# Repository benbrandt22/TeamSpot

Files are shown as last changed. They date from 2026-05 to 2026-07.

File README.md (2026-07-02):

# TeamSpot

Hardware Mute Control for Microsoft Teams

(Currently a work in progress)

## Why does this exist?

This project was created because it seemed like a fun idea for a small electronics project to try some new things. In my professional life, I use Microsoft Teams for meetings and calls. During most meetings I try to have good microphone etiquette, muting myself when I'm not speaking to minimize background noise and distractions for others. When I wanted to speak, I didn't like having to grab my mouse and find the un-mute button. Sometimes that meant extra seconds of silence before I could respond. Sometimes I'd forget I'm on mute because I had another appication active. Keyboard shortcuts didn't seem like the right solution either, as sometimes I'm using another application that's active in front of MS Teams. I was in the mood to build some hardware, so a physical button seemed like the right way to handle this.

The other key objective was to get good visual feedback of my microphone's current mute status. I wanted the device to reflect the actual status of the microphone in Teams, so that if I muted myself using the software controls, the device would show that as well.

## Hardware

- [Firmware ReadMe](src/firmware/README.md)
- [Circuit Board ReadMe](src/board/README.md)

# Software

- [Windows Service ReadMe](src/service/README.md)

## Teams Integration

My initial research revealed a local websocket API that published realtime events from Teams, and had the ability to send commands to Teams. This was originally released (I think) around 2023 and was heavily used by the Elgato Stream Deck to allow similar control and status display integration with Teams.

This local Teams API can be seen in MS Teams under Settings > Privacy > Third-Party app API.

Some related links:
- https://techcommunity.microsoft.com/blog/microsoftteamsblog/delivering-new-webinar-experiences-with-microsoft-teams/3725145
- https://github.com/malkstar/ms_teams_websockets
- https://github.com/svrooij/teams-monitor/issues/15
- https://github.com/svrooij/teams-monitor
- https://support.microsoft.com/en-us/office/connect-to-third-party-devices-in-microsoft-teams-aabca9f2-47bb-407f-9f9b-81a104a883d6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
- https://lostdomain.notion.site/Microsoft-Teams-WebSocket-API-5c042838bc3e4731bdfe679e864ab52a

When I discovered this, I also found articles/posts that revealed that Microsoft was planning on deprecating and/or removing this API, announced in late 2025. The Teams instance on my personal computer did not have this API enabled. However, my Teams installation on my work laptop did have it enabled. They were both on the same version, so something about my corporate account had this feature enabled. It could still go away someday, but for now it works and that's good enough for my little project.

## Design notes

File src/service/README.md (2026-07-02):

# TeamSpot Windows Service

This project is a Windows Service application designed to connect to Microsoft Teams as well as the TeamSpot USB device. Based on the currect state of MS Teams, this service will set the LED color on the device. This service also receives button press events from the device and reacts accordingly by sending messages to Teams to Mute or Unmute.

This service supports two types of button presses on the device:

- Short button press (1 second or less): This will toggle the mute state in Microsoft Teams. Useful for quickly muting or unmuting during a call.
- Long button press (over 1 second): This will temporarily toggle the mute state only while the button is held down. Useful when you want to temporarily mute yourself to cough, or briefly unmute for a short comment.

## How to Build/Compile

This project is set up to publish to a single executable file which can then be used as a Windows Service. To produce this executable, do one of the following:

- Using Visual Studio, right click on the `TeamSpot.Service` project and select "Publish". The Folder publish profile will be selected by default. Click the "Publish" button to create the output.
- Form a command line, navigate to the `TeamSpot.Service` project folder and run the following command:
  ```
  dotnet publish -p:PublishProfile=FolderProfile
  ```

The executable and accompanying files will be placed in the `TeamSpot.Service\bin\Release\net10.0-windows\win-x64\publish\win-x64` folder of the project. You can then use this output to install the service on your Windows machine.

## How to Install

I haven't created a proper installer for this service. Since this is currently just for me it's simple enough to manually install the executable as a Windows Service. I've simplified the process by including a script. Simply run the `install-service.bat` script included in the build output folder. You may need Administrator privileges to run this script. Within Windows, right-click on the script and select "*Run as Administrator*". This script will install the service and start it automatically. If you wish to uninstall, run the `uninstall-service.bat` script in the same manner.

## LED Color Adjustment

If you wish to change to default LED colors shown on the button for each possible state, edit the color values in the `appsettings.json` file. Colors are represented in RGB values (0-255 for each channel) as well as a brightness value of 0 to 100. The application is set up to auto-update settings if they are changed, so you can edit the file while the service is running and it will pick up the changes automatically and update the LED within a few seconds.

## Development Notes

The windows service itself is composed of a series of C# BackgroundService implementations. The main jobs of the service (listening to a Websocket API, and listening for USB device messages) are asynchronous operations that block until a message comes in. This is a challenge for communicating back and forth between the various internal services. The communication challenge is handled using ChannelReader and ChannelWriter objects to allow these async services to communicate across threads. Admittedly this is a fairly new pattern to me, so I had some help from AI to get it scaffolded out, but after working with it and refactoring it, it's been working well for this project.

Windows service project fundamentals:
- https://learn.microsoft.com/en-us/dotnet/core/extensions/windows-service

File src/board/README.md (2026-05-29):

# Circuit Board

The circuit board was designed with [KiCad](https://www.kicad.org/). I've designed boards in the past with other tools, and this was my first project in KiCad. With a little help from YouTube tutorials, I was able to get up to speed quickly.

The board contains a mix of surface mount and through-hole components. The RGB LEDs, capacitors, and resistor are all surface mount, while the microcontroller and keyboard switch are through-hole.

The schematic was inspired by the [Adafruit Neopixel Jewel](https://www.adafruit.com/product/2226), which uses a similar circuit to control RGB LEDs. The board arranges 6 WS2812B LEDs in a circular pattern, with a single data line running through each LED. The keyboard switch is soldered to the front of the board in the middle of the LEDs.

The microcontroller is mounted on the back of the board, offset from the board using pin headers/sockets. The five pins opposite of the USB plug are not included in the board design. They are not used in the circuit, and removing them leaves space to mount the keyboard switch.

Two 3mm mounitng holes are included to allow two M3 bolts to hold the board in place.

For my personal build, I ordered boards from [PCBWay](https://www.pcbway.com/) mainly for their hobbyist-friendly pricing. They also provide a KiCad plugin that makes it easy to export and upload design files and order the boards online.

## Useful Links:

- [KiCad](https://www.kicad.org/)
- [Adafruit Neopixel Jewel](https://www.adafruit.com/product/2226)
- [Neopixel Schematics and PCBs](https://learn.adafruit.com/adafruit-neopixel-uberguide/downloads)
- [RP2040-Zero Symbol/Footprint Download](https://www.snapeda.com/parts/RP2040-ZERO/Waveshare%20Electronics/view-part/)
- [PCBWay](https://www.pcbway.com/)
- [PCBWay KiCad Plugin Info](https://www.pcbway.com/blog/News/PCBWay_Plug_In_for_KiCad_3ea6219c.html)

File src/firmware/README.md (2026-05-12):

# Hardware

The hardware is based off of a RP2040-Zero microcontroller, running [CircuitPython](https://circuitpython.org/). I chose this device because:

- Supports USB HID, and I wanted to learn USB communications. USB is also simpler setup on the host PC, as I don't need to worry about choosing and configuring COM ports for serial communication
- Small footprint, so I can easily fit this into a small 3D-printable enclosure
- Low-cost. I found a 3-pack on Amazon for around $10
- CircuitPython support, which I have some past experience with. I really like the easy development-loop experience of just updating script files directly on the device.
- Includes a built-in RGB LED, which I can use for visual feedback (unless I find it's not bright enough on its own)

## Reference Images

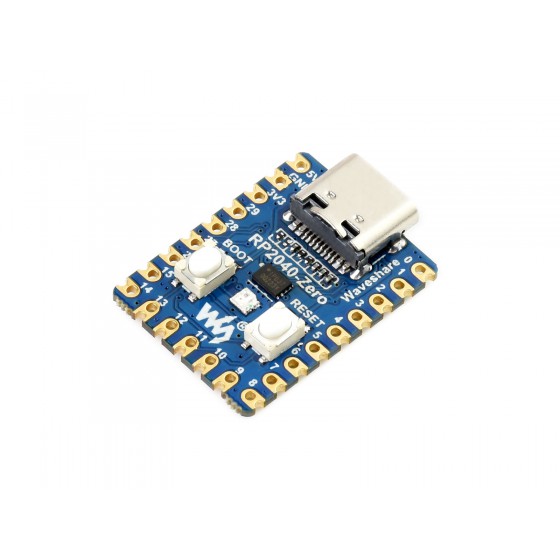
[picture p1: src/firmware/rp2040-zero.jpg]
[](rp2040-zero.jpg)
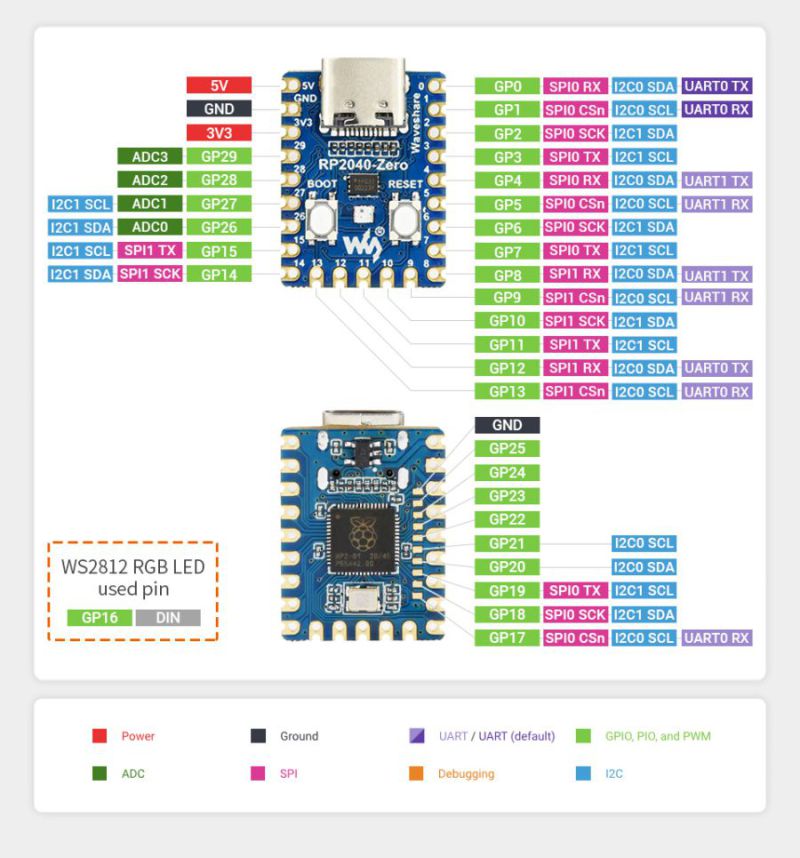
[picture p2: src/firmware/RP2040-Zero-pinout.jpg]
[](RP2040-Zero-pinout.jpg)
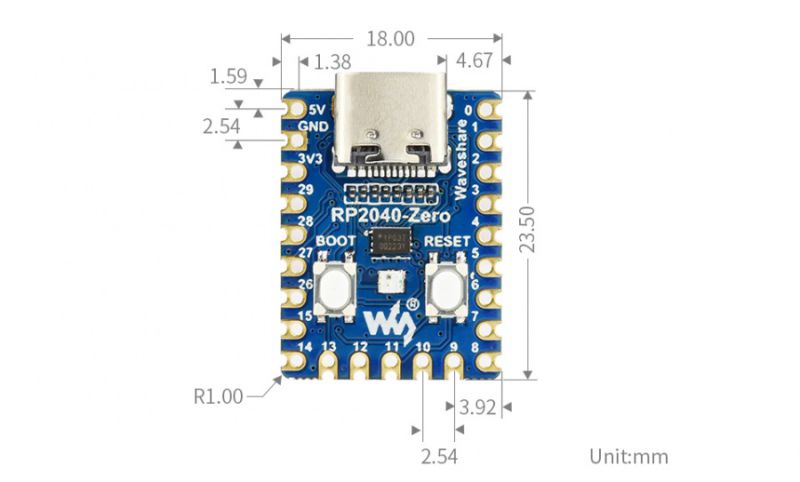
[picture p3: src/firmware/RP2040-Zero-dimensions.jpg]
[](RP2040-Zero-dimensions.jpg)

## Hardware Setup

1. Download the CircuitPython build for the RP2040-Zero: https://circuitpython.org/board/waveshare_rp2040_zero/ (Currently v10.2.0 at the time of this writing)
2. Plug the board into a USB port and copy the downloaded `.uf2` file to the drive of the RP2040-Zero
3. The device will reboot and show up as a new drive called `CIRCUITPY`

## Deploying Code

Source code for the device lives in the `device/src` directory. Make any changes there, and run the `deploy.ps1` powershell script to copy any updated files to the circuitpython drive. The script will find the circuitpython drive and copy files to it.

## USB HID Report Descriptor

USB HID (Human Interface Device) is a standard for devices that interact with humans, such as keyboards, mice, game controllers, etc. The HID report descriptor is a data structure that describes the format of the data that the device will send to the host computer. It defines the types of inputs and outputs the device has, and how they are structured. Generating these descriptors can be complex, and that's where `Waratah` comes in.

Waratah is a tool from Microsoft for generating USB HID descriptors, using a .wara file to define the HID descriptor in a more human-readable way.

Waratah Links & information

- https://github.com/microsoft/hidtools
- https://github.com/microsoft/hidtools/wiki

To install, run the command `winget install Microsoft.HIDTools.Waratah`

In this project, the `hid_descriptor` directory contains a small development environment for building the report descriptor.

- `descriptor.wara` acts as the "source code" for the descriptor
- `generate.ps1` script runs the Waratah tool to build a report descriptor from the .wara file. Waratah by default only generates a C code file, so the powershell script pulls out the raw data and builds a python-compatible byte array that can be copied into the CircuitPython project.

Other relevant USB HID links:

- https://eleccelerator.com/tutorial-about-usb-hid-report-descriptors/
- https://www.usb.org/hid
- https://docs.circuitpython.org/en/latest/shared-bindings/usb_hid/

Web-based HID Explorer tool for testing USB device:

- Github repo: https://github.com/paulirish/webhid-explorer
- Live tool: https://paulirish.github.io/webhid-explorer/

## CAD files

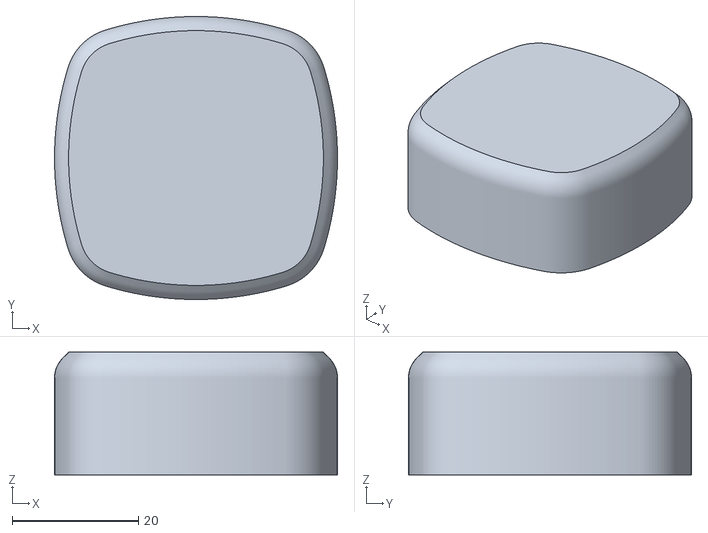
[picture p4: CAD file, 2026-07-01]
src/enclosure/teamspot-button-keycap.stl
44.8 x 44.8 x 19.4

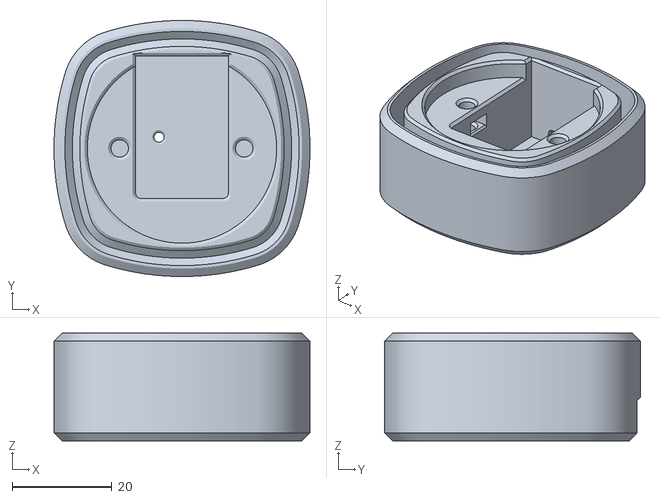
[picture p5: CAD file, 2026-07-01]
src/enclosure/teamspot-base.stl
51.4 x 51.4 x 21.6

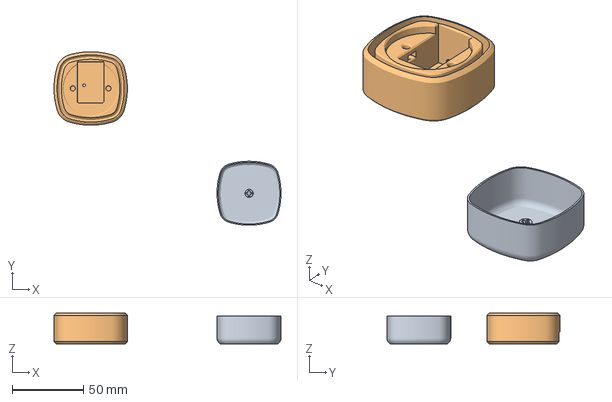
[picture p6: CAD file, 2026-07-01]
src/enclosure/teamspot-enclosure-bambu.3mf
159.0 x 121.4 x 21.6 mm
teamspot-button-keycap.stl
teamspot-base.stl

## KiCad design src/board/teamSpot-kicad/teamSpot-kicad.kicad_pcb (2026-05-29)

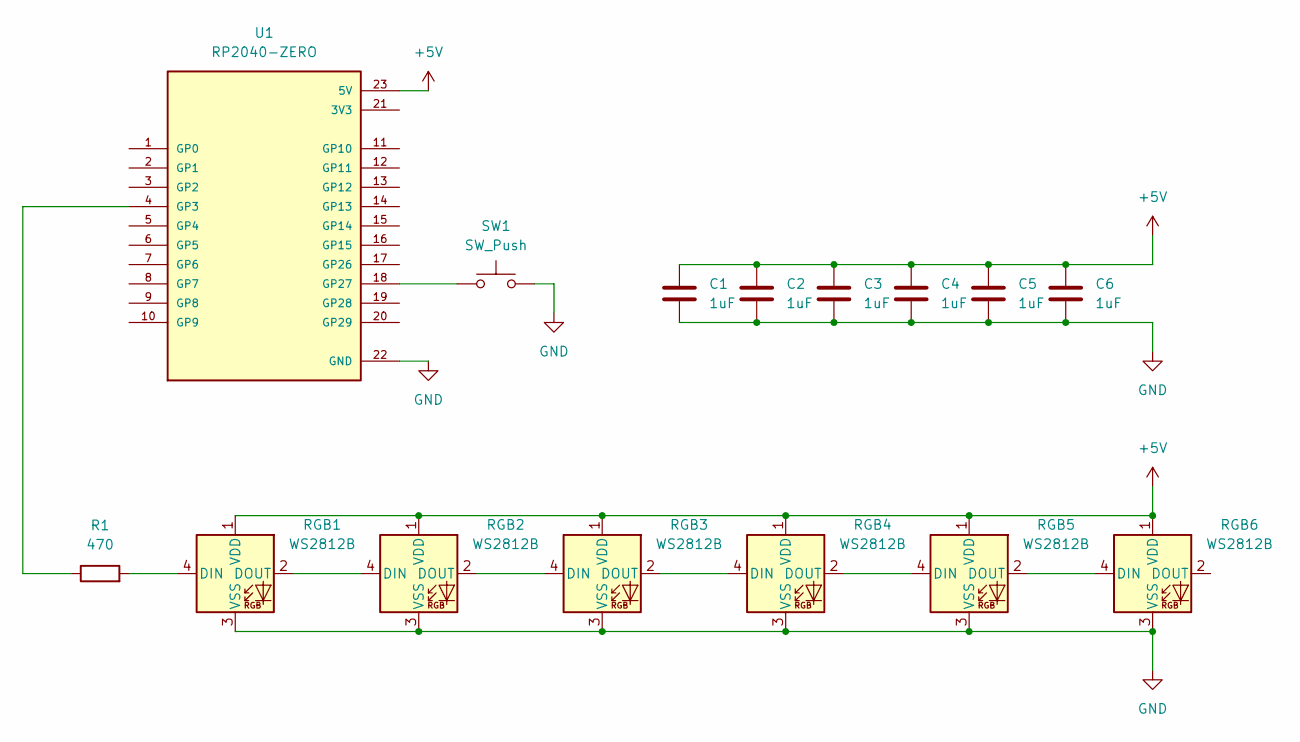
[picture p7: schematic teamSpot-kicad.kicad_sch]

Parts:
C1, C2, C3, C4, C5, C6: 1uF; C_0603_1608Metric
R1: 470; R_0603_1608Metric
RGB1, RGB2, RGB3, RGB4, RGB5, RGB6: WS2812B; LED_WS2812B_PLCC4_5.0x5.0mm_P3.2mm
SW1: SW_Push; SW_Cherry_MX_1.00u_PCB
U1: RP2040-ZERO; MODULE_RP2040-ZERO-SIDES-ONLY; PARTREV NA

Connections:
+5V: C1.1, C2.1, C3.1, C4.1, C5.1, C6.1, RGB1.1 (VDD), RGB2.1 (VDD), RGB3.1 (VDD), RGB4.1 (VDD), RGB5.1 (VDD), RGB6.1 (VDD), U1.23 (5V)
GND: C1.2, C2.2, C3.2, C4.2, C5.2, C6.2, RGB1.3 (VSS), RGB2.3 (VSS), RGB3.3 (VSS), RGB4.3 (VSS), RGB5.3 (VSS), RGB6.3 (VSS), SW1.2, U1.22 (GND)
unnamed: R1.2, RGB1.4 (DIN)
unnamed: RGB1.2 (DOUT), RGB2.4 (DIN)
unnamed: RGB2.2 (DOUT), RGB3.4 (DIN)
unnamed: RGB3.2 (DOUT), RGB4.4 (DIN)
unnamed: RGB4.2 (DOUT), RGB5.4 (DIN)
unnamed: RGB5.2 (DOUT), RGB6.4 (DIN)
unnamed: R1.1, U1.4 (GP3)
unnamed: SW1.1, U1.18 (GP27)

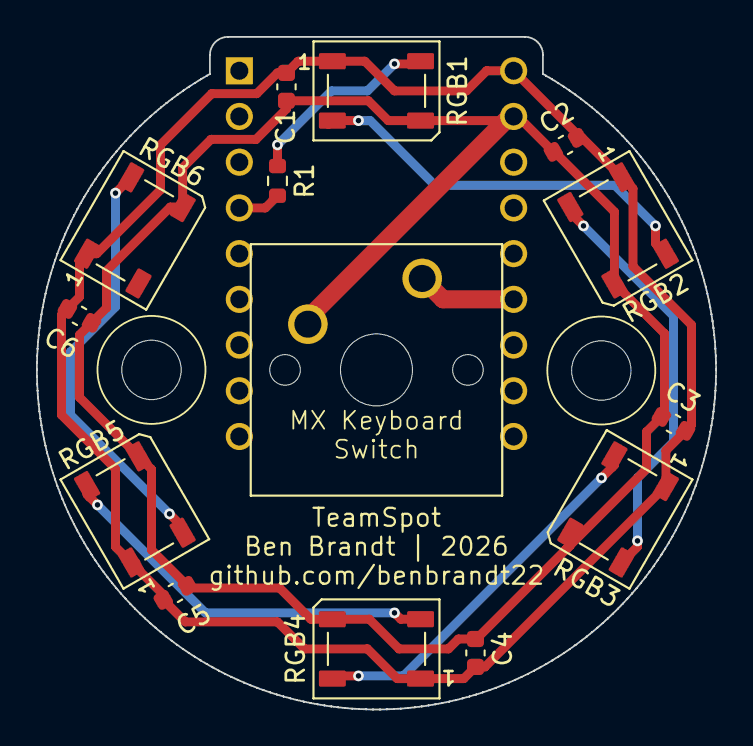
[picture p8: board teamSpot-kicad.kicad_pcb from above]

Board: 2 copper layers, 37.7 x 37.4 mm, 15 parts (1 on the bottom side), 10 nets.

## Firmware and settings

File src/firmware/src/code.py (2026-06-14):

import time
import digitalio
import neopixel
import usb_hid
import math
import pins

# Get our custom HID device
device = None

def find_device(usage_page, usage):
    for device in usb_hid.devices:
        if device.usage_page == usage_page and device.usage == usage:
            return device
    raise ValueError("Custom HID device not found")

device = find_device(usage_page=0xFF22, usage=0x01)

# ----- BUTTON SETUP -----

button = digitalio.DigitalInOut(pins.BUTTON_PIN)
button.switch_to_input(pull=digitalio.Pull.UP)

# ----- STATE TRACKING -----

last_pressed = False

# ----- NEOPIXEL SETUP -----

num_pixels = 6
pixel_pin = pins.PIXEL_PIN
pixels = neopixel.NeoPixel(pixel_pin, num_pixels, brightness=0.2, auto_write=False)

def show_color(r, g, b, brightness_percent):
    for i in range(num_pixels):
        pixels.brightness = brightness_percent / 100.0
        pixels[i] = (r, g, b)
    pixels.show()

# ----- STARTUP ANIMATION -----

def spin(color=(0, 255, 0), laps=3, speed=num_pixels, fade_laps=1): # speed = pixels/sec
    r, g, b = color
    total_distance = num_pixels * laps
    fade_start = total_distance - (num_pixels * fade_laps)
    pos = 0.0

    while pos < total_distance:
        # how far into the fade zone are we? 0.0 -> 1.0
        if pos >= fade_start:
            t = 1.0 - (pos - fade_start) / (num_pixels * fade_laps)
        else:
            t = 1.0

        lo = int(pos) % num_pixels
        hi = (lo + 1) % num_pixels
        frac = pos - math.floor(pos)

        pixels.fill((0, 0, 0))
        pixels[lo] = (round(r * (1.0 - frac) * t), round(g * (1.0 - frac) * t), round(b * (1.0 - frac) * t))
        pixels[hi] = (round(r * frac * t),          round(g * frac * t),          round(b * frac * t))
        pixels.show()

        UPDATE_RATE = 0.02 # seconds per frame
        pos += speed * UPDATE_RATE
        time.sleep(UPDATE_RATE)

    pixels.fill((0, 0, 0))
    pixels.show()


spin((0,0,255), 2)

# ----- MAIN LOOP -----

while True:

    # Buttons are active LOW
    pressed = not button.value

    # Only send report when state changes
    if pressed != last_pressed:

        report = bytearray(1)
        report[0] = 0x01 if pressed else 0x00

        device.send_report(report, report_id=1)
        time.sleep(0.05)

        last_pressed = pressed

    # --- Receive output report from host ---
    output = device.get_last_received_report(report_id=1)
    if output is not None and len(output) == 4:
        r, g, b, brightness_percent = output[0], output[1], output[2], output[3]
        show_color(r, g, b, brightness_percent)

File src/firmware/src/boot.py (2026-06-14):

import usb_hid
import digitalio
import storage
import time
import pins

# ----- USB INTERFACE -----

HID_REPORT_DESCRIPTOR = bytes((
    0x06, 0x22, 0xFF,    # UsagePage(LitButton[0xFF22])
    0x09, 0x01,          # UsageId(LitButton[0x0001])
    0xA1, 0x01,          # Collection(Application)
    0x85, 0x01,          #     ReportId(1)
    0x09, 0x02,          #     UsageId(Button[0x0002])
    0x15, 0x00,          #     LogicalMinimum(0)
    0x25, 0x01,          #     LogicalMaximum(1)
    0x95, 0x01,          #     ReportCount(1)
    0x75, 0x01,          #     ReportSize(1)
    0x81, 0x02,          #     Input(Data, Variable, Absolute, NoWrap, Linear, PreferredState, NoNullPosition, BitField)
    0x75, 0x07,          #     ReportSize(7)
    0x81, 0x03,          #     Input(Constant, Variable, Absolute, NoWrap, Linear, PreferredState, NoNullPosition, BitField)
    0x09, 0x03,          #     UsageId(RedChannel[0x0003])
    0x09, 0x04,          #     UsageId(GreenChannel[0x0004])
    0x09, 0x05,          #     UsageId(BlueChannel[0x0005])
    0x26, 0xFF, 0x00,    #     LogicalMaximum(255)
    0x95, 0x03,          #     ReportCount(3)
    0x75, 0x08,          #     ReportSize(8)
    0x91, 0x02,          #     Output(Data, Variable, Absolute, NoWrap, Linear, PreferredState, NoNullPosition, NonVolatile, BitField)
    0x09, 0x06,          #     UsageId(Brightness[0x0006])
    0x25, 0x64,          #     LogicalMaximum(100)
    0x95, 0x01,          #     ReportCount(1)
    0x75, 0x07,          #     ReportSize(7)
    0x91, 0x02,          #     Output(Data, Variable, Absolute, NoWrap, Linear, PreferredState, NoNullPosition, NonVolatile, BitField)
    0x75, 0x01,          #     ReportSize(1)
    0x91, 0x03,          #     Output(Constant, Variable, Absolute, NoWrap, Linear, PreferredState, NoNullPosition, NonVolatile, BitField)
    0xC0,                # EndCollection()
))

my_device = usb_hid.Device(
    report_descriptor=HID_REPORT_DESCRIPTOR,
    usage_page=0xFF22,
    usage=0x01,
    report_ids=(1,),
    in_report_lengths=(1,),
    out_report_lengths=(4,)
)

usb_hid.enable( (my_device,) )


# ----- USB STORAGE -----

# USB storage is enabled by default in CircuitPython. For this device we only want to enable it if the user holds the button down for awhile during startup.

button = digitalio.DigitalInOut(pins.BUTTON_PIN)
button.switch_to_input(pull=digitalio.Pull.UP)

HOLD_DURATION_SECONDS = 10

enableUsbStorage = True

if not button.value: # button is pressed
    # Button held — waiting to confirm it stays held long enough...
    start = time.monotonic()
    held = True

    while time.monotonic() - start < HOLD_DURATION_SECONDS:
        if button.value:  # released early
            held = False
            break
        time.sleep(0.10)

    if not held:
        # button released early — disable USB storage
        enableUsbStorage = False
else:
    # button wasn't held at all — disable USB storage immediately
    enableUsbStorage = False


if not enableUsbStorage:
    storage.disable_usb_drive()


button.deinit()  # release the pin before code.py runs

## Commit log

2026-05-12 Initial MVP device code with basic USB send/receive
2026-05-13 established basic windows service that reads USB button presses
2026-05-14 Added Teams integration and basic LED on/off functionality
2026-05-15 Updated device to support RGB/brightness output
2026-05-15 Updated service to send LED color commands
2026-05-15 turn off LED at service shutdown
2026-05-20 Updated to support multiple neopixel LEDs, updated startup animation
2026-05-21 Added classes to represent button state change inputs
2026-05-21 Moved USB parsing logic into the event, built framework for parsing input events
2026-05-22 Updated pin assignments
2026-05-29 Adds KiCad circuit board design
    [teamSpot-kicad.kicad_pcb, teamSpot-kicad.kicad_sch]
2026-06-12 Updated pin assignments and LED count for circuit board
2026-06-14 disable USB storage access unless button is held at startup
2026-07-01 Added 3D models for enclosure
    [teamspot-base.stl, teamspot-button-keycap.stl, teamspot-enclosure-bambu.3mf]
